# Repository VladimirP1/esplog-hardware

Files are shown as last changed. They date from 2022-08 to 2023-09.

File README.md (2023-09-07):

### What is this
These are boards for running the [esp-gyrologger](https://github.com/VladimirP1/esp-gyrologger) firmware. They contain an esp32-c3, a mems IMU and 3.3v a regulator. Wi-Fi antenna is bad, but it works at low TX power.

esplog-hv accepts 4-30v input

esplog-ldo accepts 4-6v input

### How the finished product look like
This is how esplog_ldo and esplog_hv look like

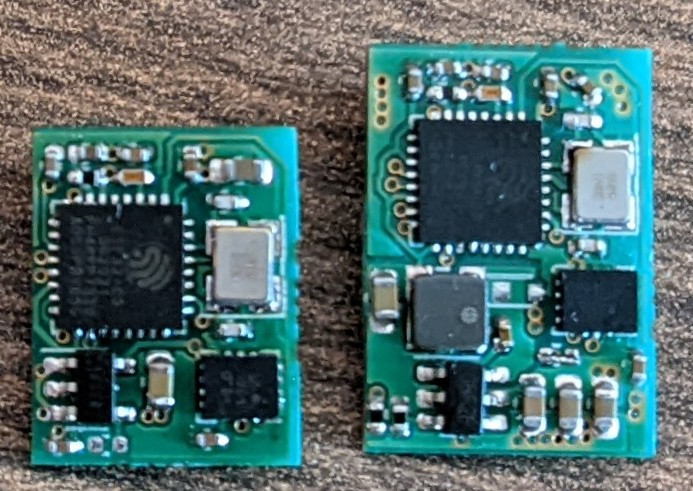
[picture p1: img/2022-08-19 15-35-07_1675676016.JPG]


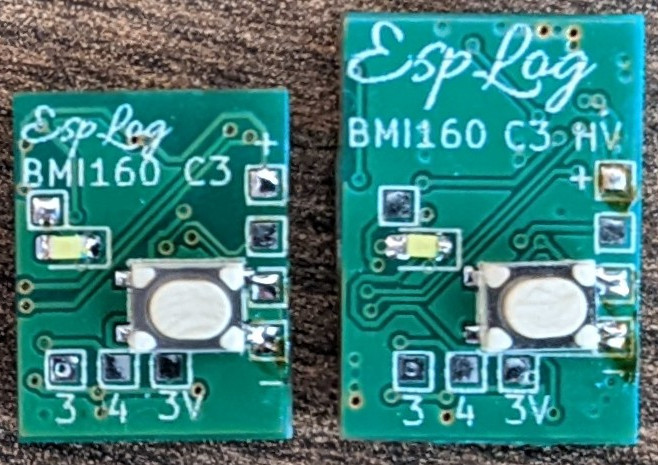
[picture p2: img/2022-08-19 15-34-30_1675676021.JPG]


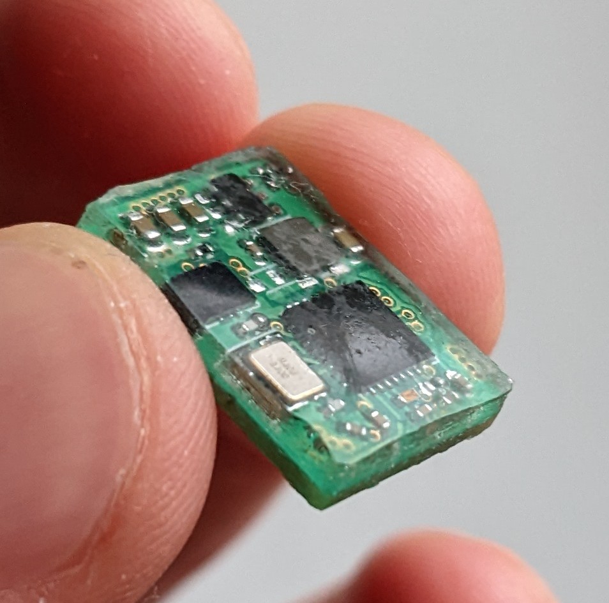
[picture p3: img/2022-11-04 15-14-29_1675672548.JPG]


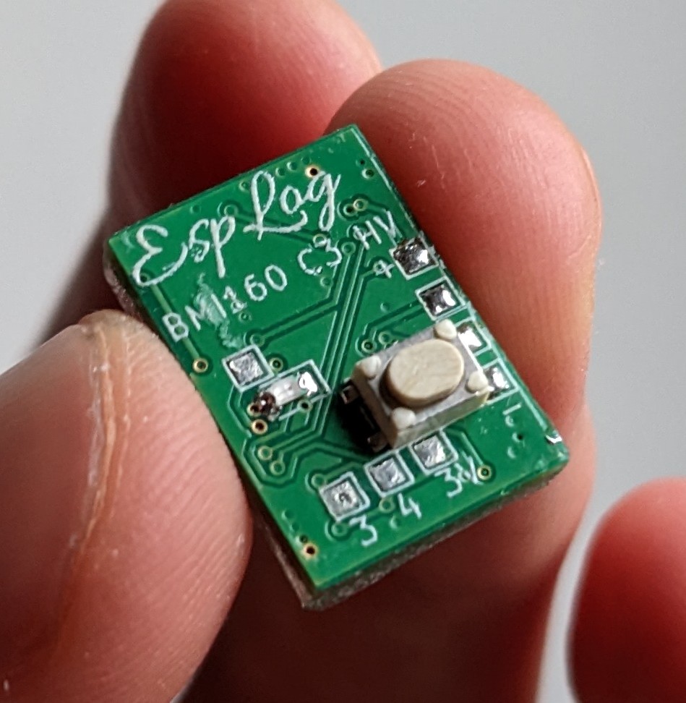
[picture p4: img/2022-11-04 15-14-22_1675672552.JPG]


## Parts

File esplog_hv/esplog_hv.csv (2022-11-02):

Id | Designator | Package | Quantity | Designation | Supplier and ref
1 | C9,C4,C8,C6,C12 | C_0402_1005Metric | 5 | 100n
2 | C2,C1 | C_0402_1005Metric | 2 | 10p
3 | R3,R4,R1 | R_0402_1005Metric | 3 | 10k
4 | U1 | QFN-32-1EP_5x5mm_P0.5mm_EP3.45x3.45mm | 1 | ESP32-C3
5 | R2 | R_0402_1005Metric | 1 | 31.6k
6 | L1 | L_0402_1005Metric | 1 | 2n
7 | IC1 | SOT-23-6 | 1 | RY8310
8 | C7 | C_0603_1608Metric | 1 | 22u
9 | C11,C14,C13 | C_0603_1608Metric | 3 | 4.7u
10 | U2 | Bosch_LGA-14_3x2.5mm_P0.5mm | 1 | BMI160
11 | Y1 | Crystal_SMD_3225-4Pin_3.2x2.5mm | 1 | 40M
12 | C3 | C_0402_1005Metric | 1 | 1u
13 | L2 | VLS3012 | 1 | VLS3012HBX-4R7M
14 | C10 | C_0402_1005Metric | 1 | C
15 | SW1 | SW_SPST_PTS810 | 1 | SW_Push
16 | D2 | LED_0603_1608Metric | 1 | LED

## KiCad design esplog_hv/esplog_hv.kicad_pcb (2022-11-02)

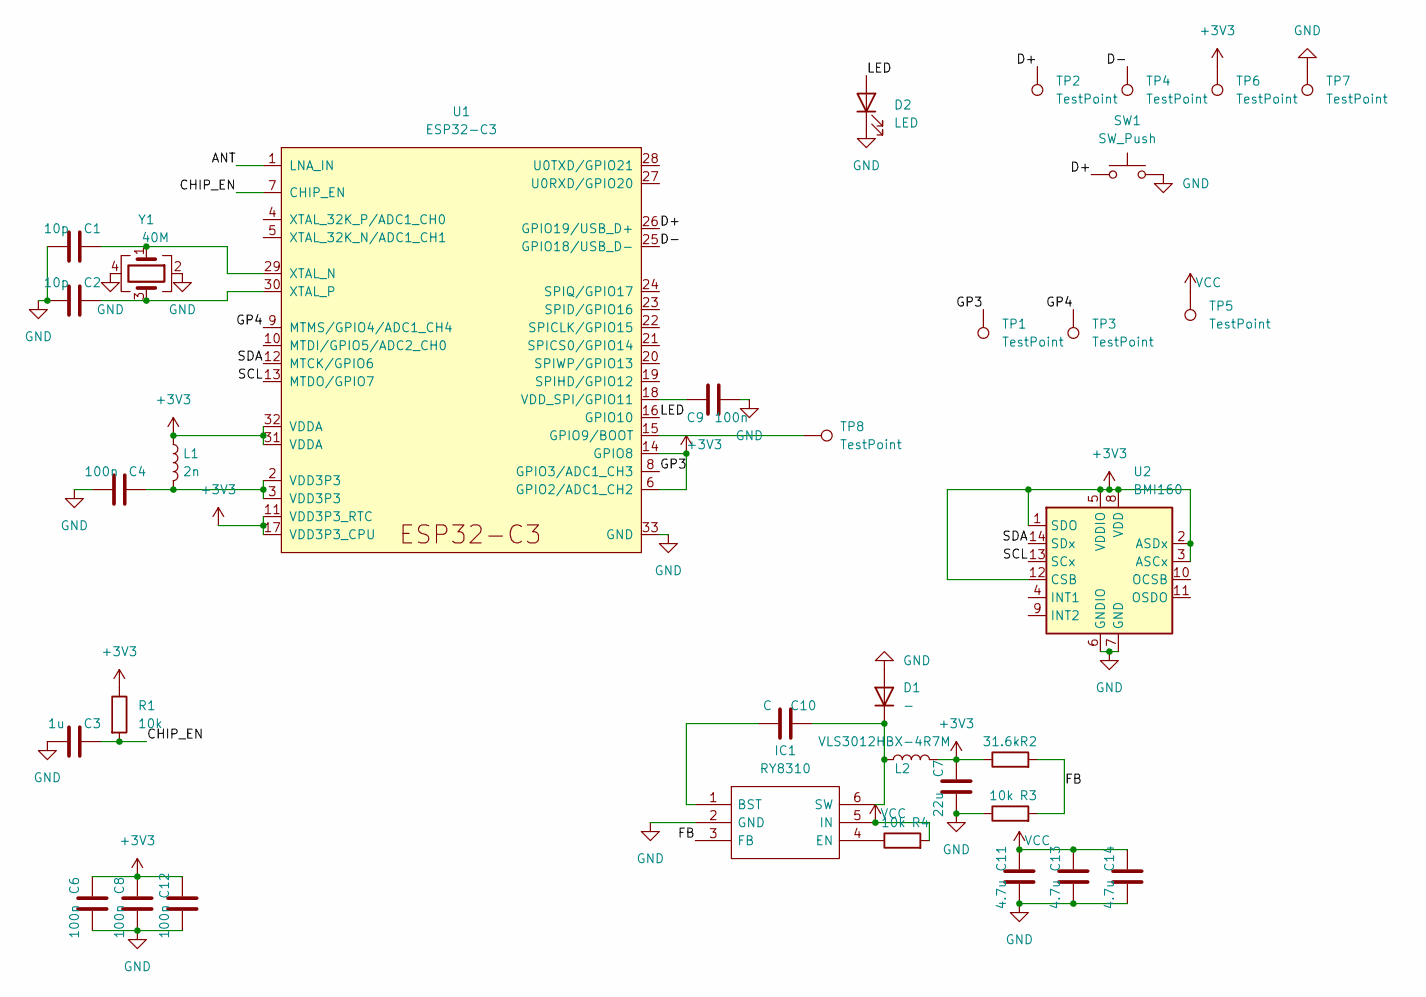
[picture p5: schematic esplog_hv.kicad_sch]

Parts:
C1, C2: 10p; C_0402_1005Metric
C3: 1u; C_0402_1005Metric
C4, C6, C8, C9, C12: 100n; C_0402_1005Metric
C7: 22u; C_0603_1608Metric
C10: C; C_0402_1005Metric
C11, C13, C14: 4.7u; C_0603_1608Metric
D1: -; D_SOD-523
D2: LED; LED_0603_1608Metric
IC1: RY8310; SOT-23-6; Mouser Part Number 946-MP2359DJLFZ
L1: 2n; L_0402_1005Metric
L2: VLS3012HBX-4R7M; VLS3012
R1, R3, R4: 10k; R_0402_1005Metric
R2: 31.6k; R_0402_1005Metric
SW1: SW_Push; SW_SPST_PTS810
TP1, TP2, TP3, TP4, TP5, TP6, TP7, TP8: TestPoint; TestPoint_Pad_1.0x1.0mm
U1: ESP32-C3; QFN-32-1EP_5x5mm_P0.5mm_EP3.45x3.45mm
U2: BMI160; Bosch_LGA-14_3x2.5mm_P0.5mm
Y1: 40M; Crystal_SMD_3225-4Pin_3.2x2.5mm

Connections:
+3V3: C6.2, C7.2, C8.2, C12.2, L1.1, L2.2, R1.1, R2.1, TP6.1, U1.6 (GPIO2/ADC1_CH2), U1.11 (VDD3P3_RTC), U1.14 (GPIO8), U1.17 (VDD3P3_CPU), U1.31 (VDDA), U1.32 (VDDA), U2.1 (SDO), U2.2 (ASDx), U2.3 (ASCx), U2.5 (VDDIO), U2.8 (VDD), U2.12 (CSB)
/ANT: U1.1 (LNA_IN)
/CHIP_EN: C3.2, R1.2, U1.7 (CHIP_EN)
/D+: SW1.1, TP2.1, U1.26 (GPIO19/USB_D+)
/D-: TP4.1, U1.25 (GPIO18/USB_D-)
/FB: IC1.3 (FB), R2.2, R3.2
/GP3: TP1.1, U1.8 (GPIO3/ADC1_CH3)
/GP4: TP3.1, U1.9 (MTMS/GPIO4/ADC1_CH4)
/LED: D2.2 (A), U1.16 (GPIO10)
/SCL: U1.13 (MTDO/GPIO7), U2.13 (SCx)
/SDA: U1.12 (MTCK/GPIO6), U2.14 (SDx)
GND: C1.1, C2.1, C3.1, C4.1, C6.1, C7.1, C8.1, C9.1, C11.1, C12.1, C13.1, C14.1, D1.2 (A), D2.1 (K), IC1.2 (GND), R3.1, SW1.2, TP7.1, U1.33 (GND), U2.6 (GNDIO), U2.7 (GND), Y1.2, Y1.4
unnamed: C1.2, U1.29 (XTAL_N), Y1.1
unnamed: C2.2, U1.30 (XTAL_P), Y1.3
unnamed: C4.2, L1.2, U1.2 (VDD3P3), U1.3 (VDD3P3)
unnamed: C9.2, U1.18 (VDD_SPI/GPIO11)
unnamed: C10.1, IC1.1 (BST)
unnamed: C10.2, D1.1 (K), IC1.6 (SW), L2.1
unnamed: IC1.4 (EN), R4.1
unnamed: TP8.1, U1.15 (GPIO9/BOOT)
VCC: C11.2, C13.2, C14.2, IC1.5 (IN), R4.2, TP5.1

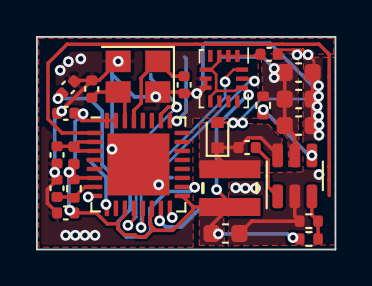
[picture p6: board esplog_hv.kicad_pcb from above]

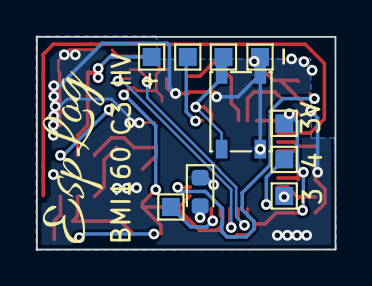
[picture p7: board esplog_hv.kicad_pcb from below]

Board: 2 copper layers, 16.6 x 11.8 mm, 34 parts (10 on the bottom side), 20 nets.

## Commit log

2022-08-30 Remove ground polygon under antenna
    [esplog_ldo.kicad_pcb]
2022-08-30 Add component values
    [esplog_hv.kicad_pcb, esplog_hv.kicad_sch, esplog_ldo.kicad_pcb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]
2022-11-01 esplog_hv: change the capacitor value on chip_en to 1u
    [esplog_hv.kicad_pcb, esplog_hv.kicad_sch]
2022-11-02 add gerbers for esplog-hv
    [esplog_hv-B_Cu.gbr, esplog_hv-B_Mask.gbr, esplog_hv-B_Paste.gbr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]
